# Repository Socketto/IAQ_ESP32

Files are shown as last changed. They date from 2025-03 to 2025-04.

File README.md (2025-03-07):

This board, designed with KiCad and programmed with Arduino, features an ESP-32 WROOM.  

The board can read CO2, TVOC, humidity, atmospheric pressure, and altitude values from multiple SPI sensors. The CO2 sensor used is the CCS811, and the board allows for the installation of two sensors, distinguished by different addresses.  
  
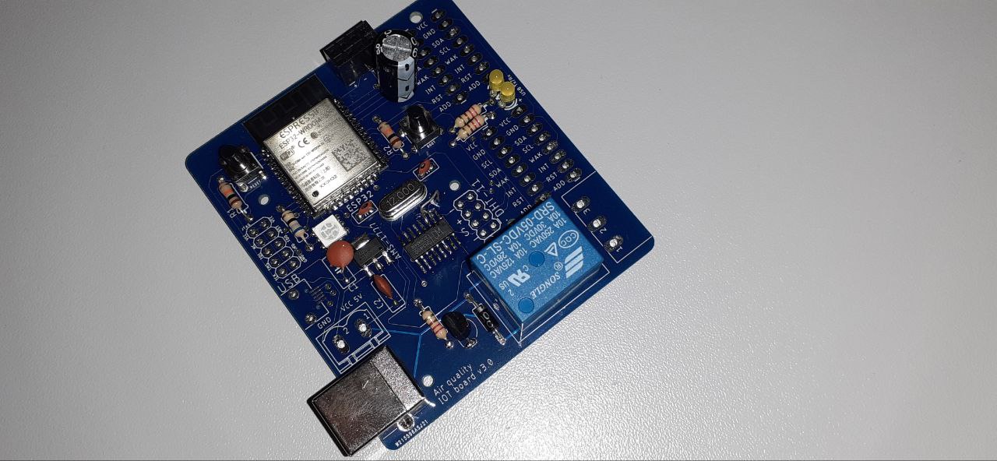
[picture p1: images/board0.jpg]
Board1
  
  
For programming, an external serial converter can be used, or it can be programmed directly via the USB port using the CH340G, which is mounted at the center of the board.  
  
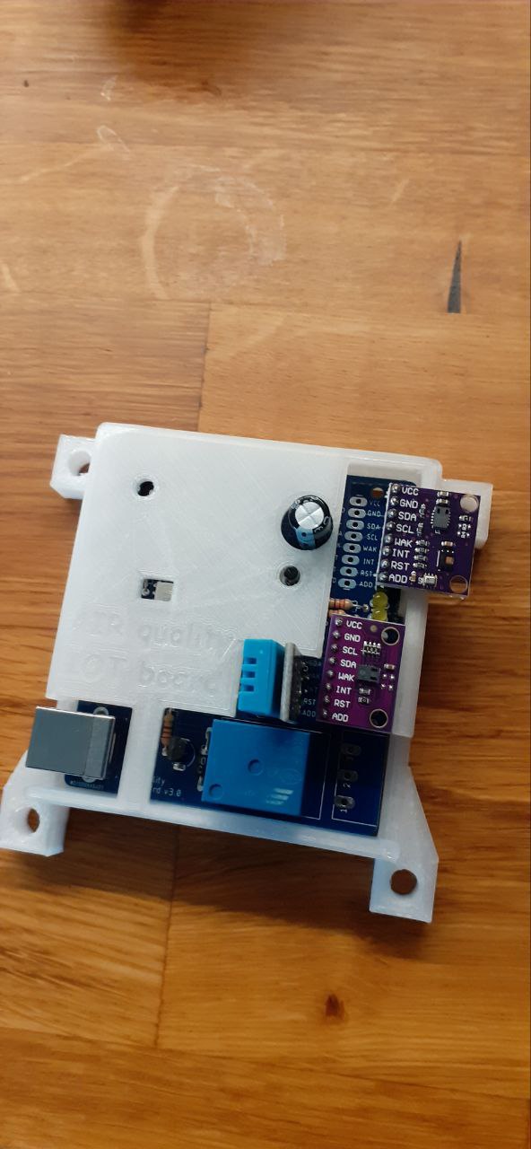
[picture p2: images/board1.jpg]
Board1


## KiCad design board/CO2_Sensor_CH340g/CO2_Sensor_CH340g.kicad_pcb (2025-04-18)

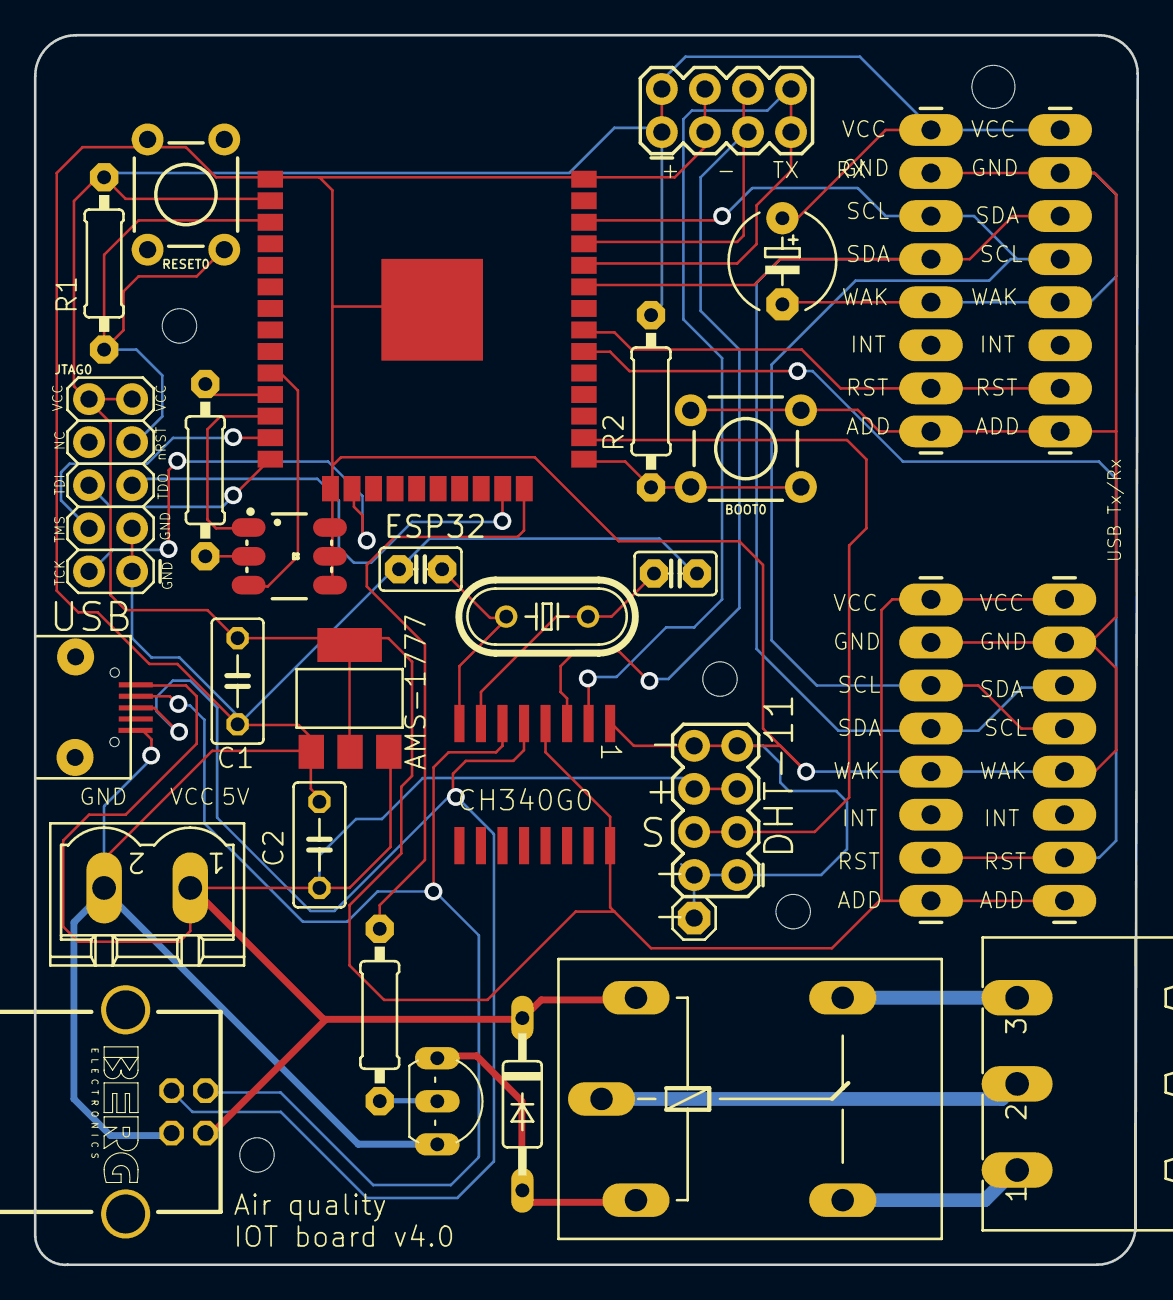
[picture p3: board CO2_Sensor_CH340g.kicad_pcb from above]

Board: 2 copper layers, 65.0 x 72.5 mm, 36 parts (0 on the bottom side), 10 nets.

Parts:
AMS-1777: 3.3v; SOT223_111
BC547: BC547; TO92-_398
BOOT0: TACTILE_SWITCH_PTH_6.0MM_535
C1, C2: 100uF; C050-030X075_420
CH340G0: SOP16_338
D2: C2992_210
E$1, E$3, E$4, E$6: 1X08_LONGPADS_513
E$2, E$9: 2X4_513
E$5: MSTBV2_176
E$7: LED-TRICOLOR-5050_529
E$8: 1X01_420
E$10: MICR-USB
E$11: 12Mhz; HC49_S_204
E$12, E$13: 22pf; C025-025X050_420
E$15: G5LE_339
E$17: MSTBA3_176
E$18: 1000uf; E5-6_420
E$19: PN61729-S_130
ESP32: ESP-WROOM-32
JTAG0: 2X5_513
R1, R2: 10k; 0207_10_420
R3: 220; 0207_10_420
R4: 68Ω; 0207_10_420
RESET0: TACTILE_SWITCH_PTH_6.0MM_535
UNK_HOLE_0: dummyfp0
UNK_HOLE_1: dummyfp1
UNK_HOLE_2: dummyfp2
UNK_HOLE_3: dummyfp3
UNK_HOLE_4: dummyfp4

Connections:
S$13: E$3.5, E$6.6
S$15: E$1.6, E$4.5
S$16: E$1.4, E$4.4
S$23: JTAG0.7, R1.1
S$26: E$2.1, E$2.2
S$29: E$8.1, E$9.2, E$9.7
S$43: E$2.4, E$3.4, E$3.7, E$4.7
S$64: E$3.1, E$3.8
S$94: JTAG0.9, JTAG0.10
S$95: C1.1, JTAG0.1, JTAG0.3

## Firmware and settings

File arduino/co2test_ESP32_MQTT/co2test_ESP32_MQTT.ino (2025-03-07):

#include "Wire.h"
#include "ClosedCube_HDC1080.h"
#include <WiFi.h>
#include <PubSubClient.h>
#include <Adafruit_BMP280.h>
#include "SparkFunCCS811.h"

#define AVGCo2 5

#include "DHT.h"

#define DHTPIN 4
#define DHTTYPE DHT11

#define BMP280_I2C_ADDRESS  0x76

Adafruit_BMP280 bmp; // I2C
DHT dht(DHTPIN, DHTTYPE);
float tDHT;
float hDHT;

float tempBMP;
float pressBMP;
float altitudeBMP;

ClosedCube_HDC1080 hdc1080;

int debug_MQTT = 0;

float temperatureVariable = 25.0; //in degrees C
float humidityVariable = 65.0; //in % relative

const char* ssid     = "ssid1";
const char* ssid2    = "ssid2";
const char* password = "pdw";

#define CCS811_ADDR 0x5B //Default I2C Address
#define CCS811_ADDR2 0x5A //Alternate I2C Address
String Body;
CCS811 myCCS811(CCS811_ADDR);
CCS811 myCCS8112(CCS811_ADDR2);

const char* mqtt_server = "192.168.1.12";
WiFiClient espClient;
PubSubClient client(espClient);
String tempString;
char buffertempString[100];

String CO2;
int CO2IsValid = 0;
String CO2_VAR;
float CO2real[AVGCo2];
float temppCO2;
float temppCO2_2;
double Co2Result;
int i;
String TVCO2;
String Temperature;
unsigned long volte = 0;
String Humidity;

void printSensorError()
{
  uint8_t error = myCCS811.getErrorRegister();

  if ( error == 0xFF ) //comm error
  {
    Serial.println("Failed to get ERROR_ID register.");
    volte = 2000;
  }
  else
  {
    Serial.print("Error: ");
    if (error & 1 << 5) Serial.print("HeaterSupply");
    if (error & 1 << 4) Serial.print("HeaterFault");
    if (error & 1 << 3) Serial.print("MaxResistance");
    if (error & 1 << 2) Serial.print("MeasModeInvalid");
    if (error & 1 << 1) Serial.print("ReadRegInvalid");
    if (error & 1 << 0) Serial.print("MsgInvalid");
    Serial.println();
  }
}

void ResetLedRGB()
{
  digitalWrite(25, LOW);
  digitalWrite(26, LOW);
  digitalWrite(27, LOW);
}

void Blue()
{
  digitalWrite(27, HIGH);
}

void Red()
{
  digitalWrite(26, HIGH);
}

void Green()
{
  digitalWrite(25, HIGH);
}


void CheckWIFI()
{
  unsigned char resetRequired = 0;
  while (WiFi.status() != WL_CONNECTED) {
    volte++;
    resetRequired = 1;

    if (volte == 1)
    {
      WiFi.begin(ssid2, password);
      Serial.println("Connecting to ");
      Serial.println(ssid2);
      Serial.println(password);
      Serial.println();
    }
    else
    {
      if (volte == 200)
      {
        WiFi.begin(ssid, password);
        Serial.println("Connecting to ");
        Serial.println(ssid);
        Serial.println(password);
        Serial.println();
      }
      if (volte >= 300)
      {
        volte = 0;
      }
    }

    delay(100);
    Red();
    delay(100);
    Serial.print(".");
    ResetLedRGB();
  }
  if (resetRequired == 1)
  {
    volte = 1995;
  }
}

void setup()
{
  pinMode(19, OUTPUT);

  pinMode(0, INPUT); //boot

  pinMode(2, OUTPUT); //RELE

  pinMode(25, OUTPUT);
  pinMode(26, OUTPUT);
  pinMode(27, OUTPUT);
  Red();
  Green();
  Blue();
  digitalWrite(19, LOW); // sets the digital pin 13 on
  delay(500);            // waits for a second
  digitalWrite(19, HIGH); // sets the digital pin 13 on
  delay(2000);            // waits for a second

  Serial.begin(115200);
  Serial.println("CCS811 EnvironmentalReadings Example");
  Serial.println("ClosedCube HDC1080 Arduino Test");

  Wire.begin();

  IPAddress ip(192, 168, 1, 9);
  IPAddress gateway(192, 168, 1, 254);
  IPAddress subnet(255, 255, 255, 0);
  WiFi.config(ip, gateway, subnet);

  if (!bmp.begin(BMP280_I2C_ADDRESS)) {
    Serial.println(F("Could not find a valid BMP280 sensor, check wiring!"));
  }

  /* Default settings from datasheet. */
  bmp.setSampling(Adafruit_BMP280::MODE_NORMAL,     /* Operating Mode. */
                  Adafruit_BMP280::SAMPLING_X2,     /* Temp. oversampling */
                  Adafruit_BMP280::SAMPLING_X16,    /* Pressure oversampling */
                  Adafruit_BMP280::FILTER_X16,      /* Filtering. */
                  Adafruit_BMP280::STANDBY_MS_500); /* Standby time. */


  //This begins the CCS811 sensor and prints error status of .begin()
  int returnCode = myCCS811.begin();
  Serial.println("myCSS811_1 begin exited with: " + returnCode);
  Serial.println("\n");
  returnCode = myCCS8112.begin();
  Serial.println("myCSS811_2 begin exited with: " + returnCode);
  if (returnCode == 0)
  {
    volte = 2000;
  }
  Serial.println(returnCode);
  Serial.println();

  // Default settings:
  //  - Heater off
  //  - 14 bit Temperature and Humidity Measurement Resolutions
  hdc1080.begin(0x40);


  Serial.print("Manufacturer ID=0x");
  Serial.println(hdc1080.readManufacturerId(), HEX); // 0x5449 ID of Texas Instruments
  Serial.print("Device ID=0x");
  Serial.println(hdc1080.readDeviceId(), HEX); // 0x1050 ID of the device


  // Connect to Wi-Fi network with SSID and password

  CheckWIFI();

  client.setServer(mqtt_server, 1883);

  // Print local IP address and start web server
  Serial.println("");
  Serial.println("WiFi connected.");
  Serial.println("IP address: ");
  Serial.println(WiFi.localIP());
  dht.begin();
  volte = 2000;
}

void reconnect() {
  int o = 0;
  // Loop until we're reconnected
  while (!client.connected())
  {
    CheckWIFI();
    Serial.print("Attempting MQTT connection...");
    // Attempt to connect
    if (client.connect("Co2BoardClient", "mqtt_user", "password"))
    {
      if (client.connected())
      {
        Serial.println("now is connected");
        delay(250);
        Green();
        delay(500);
        ResetLedRGB();
        volte = 1995;
        return;
      }
      else
      {
        Serial.println("ERROR 1");
      }
    }
    else
    {
      Serial.print("failed, rc=");
      Serial.print(client.state());
      Serial.println(" try again in 5 seconds");
      // Wait 5 seconds before retrying
      for (o = 0; o < 6; o++)
      {
        delay(250);
        Red();
        Blue();
        delay(250);
        ResetLedRGB();
      }
    }
  }
}

void loop()
{
  int o;
  CheckWIFI();
  Serial.println();
  humidityVariable = (float)hdc1080.readHumidity();
  temperatureVariable = (float)hdc1080.readTemperature();

  Serial.println("New humidity and temperature:");
  Serial.print("  Humidity: ");
  Humidity = humidityVariable;
  Serial.print(humidityVariable, 2);
  Serial.println("% relative");
  Serial.print("  Temperature: ");
  Temperature = temperatureVariable;
  Serial.print(temperatureVariable, 2);
  Serial.println(" degrees C");
  if (digitalRead(0) == 0)
  {
    digitalWrite(2, HIGH);
    debug_MQTT = 1;
  }
  else
  {
    digitalWrite(2, LOW);
  }

  if (temppCO2 > 1500 || digitalRead(0) == 0)
  {
    volte = 2000;
    temppCO2 = 0;
    CO2IsValid = 0;
  }

  volte = volte + 1;
  if (volte > 2000)
  {
    digitalWrite(2, HIGH);
    ResetLedRGB();
    Blue();
    Green();
    digitalWrite(19, LOW); // sets the digital pin 13 on
    delay(1000);            // waits for a second
    digitalWrite(19, HIGH); // sets the digital pin 13 on
    delay(3000);            // waits for a second
    int returnCode = myCCS811.begin();
    Serial.println("CCS811_1 begin exited with: " + returnCode);
    Serial.println("\n");
    returnCode = myCCS8112.begin();
    Serial.println("CCS811_2 begin exited with: " + returnCode);

    Serial.println(returnCode);
    Serial.println();
    hdc1080.begin(0x40);
    if (!bmp.begin(BMP280_I2C_ADDRESS)) {
      Serial.println(F("Could not find a valid BMP280 sensor, check wiring!"));
    }

    /* Default settings from datasheet. */
    bmp.setSampling(Adafruit_BMP280::MODE_NORMAL,     /* Operating Mode. */
                    Adafruit_BMP280::SAMPLING_X2,     /* Temp. oversampling */
                    Adafruit_BMP280::SAMPLING_X16,    /* Pressure oversampling */
                    Adafruit_BMP280::FILTER_X16,      /* Filtering. */
                    Adafruit_BMP280::STANDBY_MS_500); /* Standby time. */


    myCCS811.setEnvironmentalData(humidityVariable, temperatureVariable);
    myCCS8112.setEnvironmentalData(humidityVariable, temperatureVariable);

    //Serial.println("Environmental data applied!");
    myCCS811.readAlgorithmResults(); //Dump a reading and wait
    myCCS8112.readAlgorithmResults(); //Dump a reading and wait
    delay(500);
    ResetLedRGB();
    volte = 0;
    if (returnCode == 0)
    {
      volte = 1990;
    }
    CO2IsValid = 0;
  }
  delay(1000);

  digitalWrite(2, LOW);
  //Serial.println("Environmental data applied!");

  if (myCCS811.dataAvailable() && myCCS8112.dataAvailable())
  {
    //Calling readAlgorithmResults() function updates the global tVOC and CO2 variables
    myCCS811.readAlgorithmResults();
    myCCS8112.readAlgorithmResults();
    temppCO2 = myCCS811.getCO2();
    temppCO2_2 = myCCS8112.getCO2();
    Serial.print("\n\n");
    Serial.print(temppCO2);
    Serial.print("  -  ");
    Serial.print(temppCO2_2);
    Serial.print("\n\n");

    if (temppCO2 > 401 && (abs(temppCO2 - temppCO2_2) < 100))
    {
      Serial.print("CO2[now: ");
      for (i = AVGCo2; i > 0 ; i--)
      {
        CO2real[i] = CO2real[i - 1];
      }
      CO2real[0] = (temppCO2 + temppCO2_2) / 2;
      Co2Result = 0;
      for (i = 0; i < AVGCo2 ; i++)
      {
        Co2Result += CO2real[i];
      }
      Co2Result /= AVGCo2;
      CO2 = Co2Result;
      CO2_VAR = abs(Co2Result - CO2real[0]);
      Serial.print(CO2real[0]);
      Serial.print(" - AVG: ");
      Serial.print(CO2);
      Serial.print("] tVOC[");
      TVCO2 = myCCS811.getTVOC();
      Serial.print(TVCO2);
      Serial.print("] millis[");
      Serial.print(millis());
      Serial.print("]");
      Serial.println();
      CO2IsValid = 1;
    }
    else
    {
      CO2IsValid = 0;
    }
  }
  else if (myCCS811.checkForStatusError())
  {
    printSensorError();
    CO2IsValid = 0;
  }
  if (CO2real[AVGCo2 - 1] != 0 && CO2IsValid == 1)
  {
    Blue();
    tempString = "{";
    tempString += "\"CO2\" : \"" + CO2;
    tempString += "\",";
    tempString += "\"CO2_VAR\" : \"" + CO2_VAR;
    tempString += "\",";
    tempString += "\"TVOC\" : \"" + TVCO2;
    tempString += "\",";
    tempString += "\"Temperature\" : \"" + Temperature;
    tempString += "\",";
    tempString += "\"Hum\" : \"" + Humidity;
    tempString += "\"}";
    tempString.toCharArray(buffertempString, 100);
    while (!client.connected())
    {
      Serial.print("On loop client not connected...");
      reconnect();
    }

    client.publish("CO2Board", buffertempString);



    tempString = "{";
    tempString += "\"TemperatureDHT11\" : \"";
    tDHT = dht.readTemperature();
    tempString += tDHT;
    tempString += "\",";
    tempString += "\"HumDHT11\" : \"";
    hDHT = dht.readHumidity();
    tempString += hDHT;
    tempString += "\",";
    tempString += "\"HeatIndexDHT11\" : \"";
    tempString += dht.computeHeatIndex(tDHT, hDHT, false);
    tempString += "\"}";
    tempString.toCharArray(buffertempString, 100);
    if (!isnan(tDHT) && !isnan(hDHT))
      client.publish("CO2Board_DHT11", buffertempString);


    tempBMP = bmp.readTemperature();
    pressBMP = bmp.readPressure();
    altitudeBMP = bmp.readAltitude(1013.25) + 77;
    if (!isnan(tempBMP) && !isnan(pressBMP))
    {
      tempString = "{";
      tempString += "\"Temp\" : \"";
      tempString += tempBMP;
      tempString += "\",";
      tempString += "\"Press\" : \"";
      tempString += pressBMP / 100;
      tempString += "\",";
      tempString += "\"Alt\" : \"";
      tempString += altitudeBMP;
      tempString += "\"}";
      tempString.toCharArray(buffertempString, 100);
      client.publish("CO2Board_BMP280", buffertempString);

      Serial.print("Temperature = ");
      Serial.print(tempBMP);
      Serial.println(" °C");
      // 2: print pressure
      Serial.print("Pressure    = ");
      Serial.print(pressBMP / 100);
      Serial.println(" hPa");
      // 3: print altitude
      Serial.print("Approx Altitude = ");
      Serial.print(altitudeBMP);
      Serial.println(" m");
    }
    client.loop();
    delay(80);
    ResetLedRGB();
    delay(3000);
  }

  if (Co2Result > 401 && CO2real[AVGCo2 - 1] != 0) //valid
  {
    if (Co2Result < 600)
    {
      Green();
    }
    else
    {
      if (Co2Result < 850)
      {
        Red();
        Green();
      }
      else
      {
        Red();
      }
    }
    delay(150);
    ResetLedRGB();
  }
  else
  {
    if (Co2Result <= 400 || CO2real[AVGCo2 - 1] == 0) //not valid
    {
      for (o = 1; o < 4; o++)
      {
        Red();
        delay(100);
        Blue();
        delay(100);
        ResetLedRGB();
      }
    }
  }
}

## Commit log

2025-03-07 [ADD] First commit
    [CO2_Sensor_CH340g.brd]
2025-04-18 [UPD] Update board
    [CO2_Sensor_CH340g.kicad_pcb]
